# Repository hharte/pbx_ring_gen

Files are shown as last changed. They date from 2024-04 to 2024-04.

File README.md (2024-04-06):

# PBX Ring Generator

This project is a small carrier board for the Power DSine [PCR-SIN06V24F00](https://www.microsemi.com/document-portal/doc_view/10615-pcr-sin06series-datasheet) 4W Ring Generator.  It takes -24VDC as input and supplies isolated 86Vrms / 20Hz ringing current at 4 REN.

Stuffing options are provided for DC-biasing the output.

The board is 1.75”H x 3.93”W for mounting on a 2” relay panel such as the [WE 755A PBX Power Supply](https://github.com/hharte/we755a_ps).

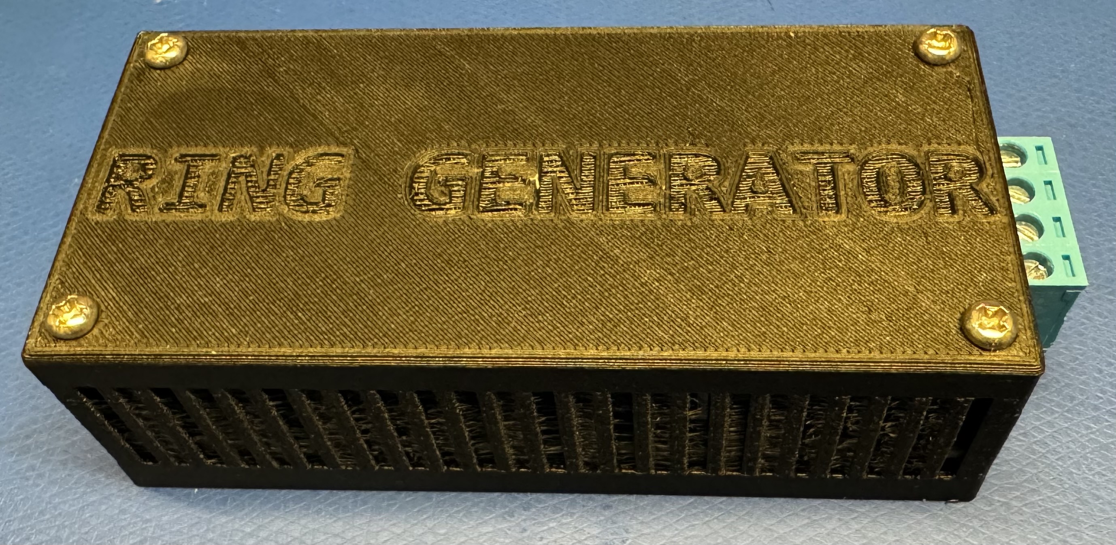
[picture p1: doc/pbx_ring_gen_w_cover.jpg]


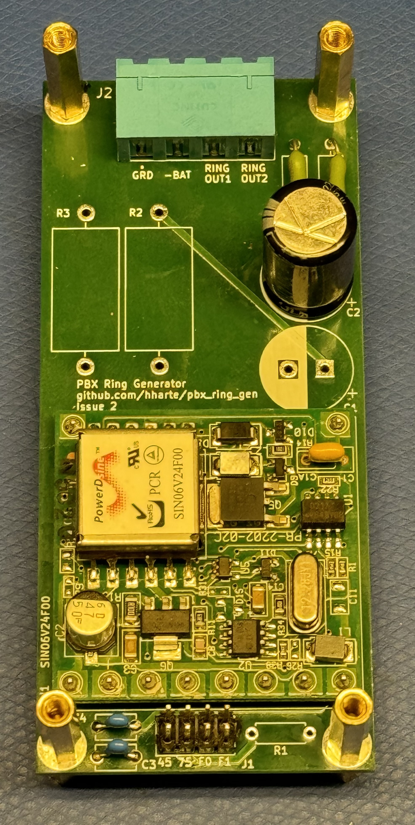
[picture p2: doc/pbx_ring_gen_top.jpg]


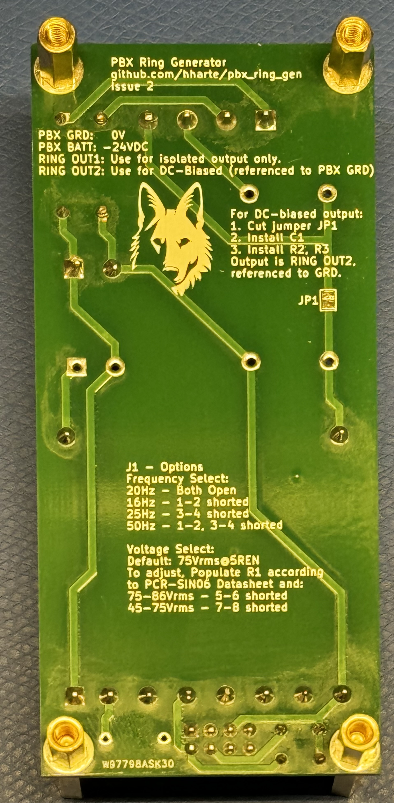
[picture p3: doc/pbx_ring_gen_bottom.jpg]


# Hardware

## PC Board Bill of Materials

[Interactive BOM](https://html-preview.github.io/?url=https://github.com/hharte/pbx_ring_gen/blob/main/hardware/bom/ibom.html)

[Digi-Key Parts List](https://www.digikey.com/en/mylists/list/BBLJD8V3Z4)

## Cover

A 3D-printed cover is included.  [For safety](https://en.wikipedia.org/wiki/UL_94), it’s a good idea to print this using [V-0 PETG](https://prusament.com/materials/prusament-petg-v0/). To mount the board with cover, use 4ea M3-10mm male/female standoffs for the bottom side of the board.  Use 4ea M3-20mm female standoffs for the top side of the board.  Mount the cover with 4ea M3 screws.

# References

* [PCR-SIN06V24F00 Datasheet](https://www.microsemi.com/document-portal/doc_view/10615-pcr-sin06series-datasheet)
* [Telephone Ring Voltage Tech Bulletin](https://www.sandman.com/knowledgebase/ring-voltage-tech-bulletin)

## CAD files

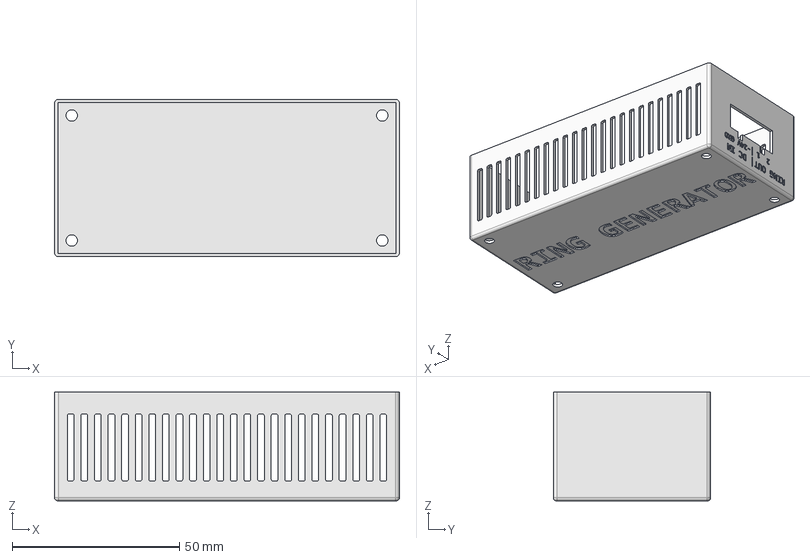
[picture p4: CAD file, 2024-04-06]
enclosure/pbx_ring_gen_cover.FCStd
103.0 x 47.0 x 32.5 mm

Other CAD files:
enclosure/pbx_ring_gen_cover.stl

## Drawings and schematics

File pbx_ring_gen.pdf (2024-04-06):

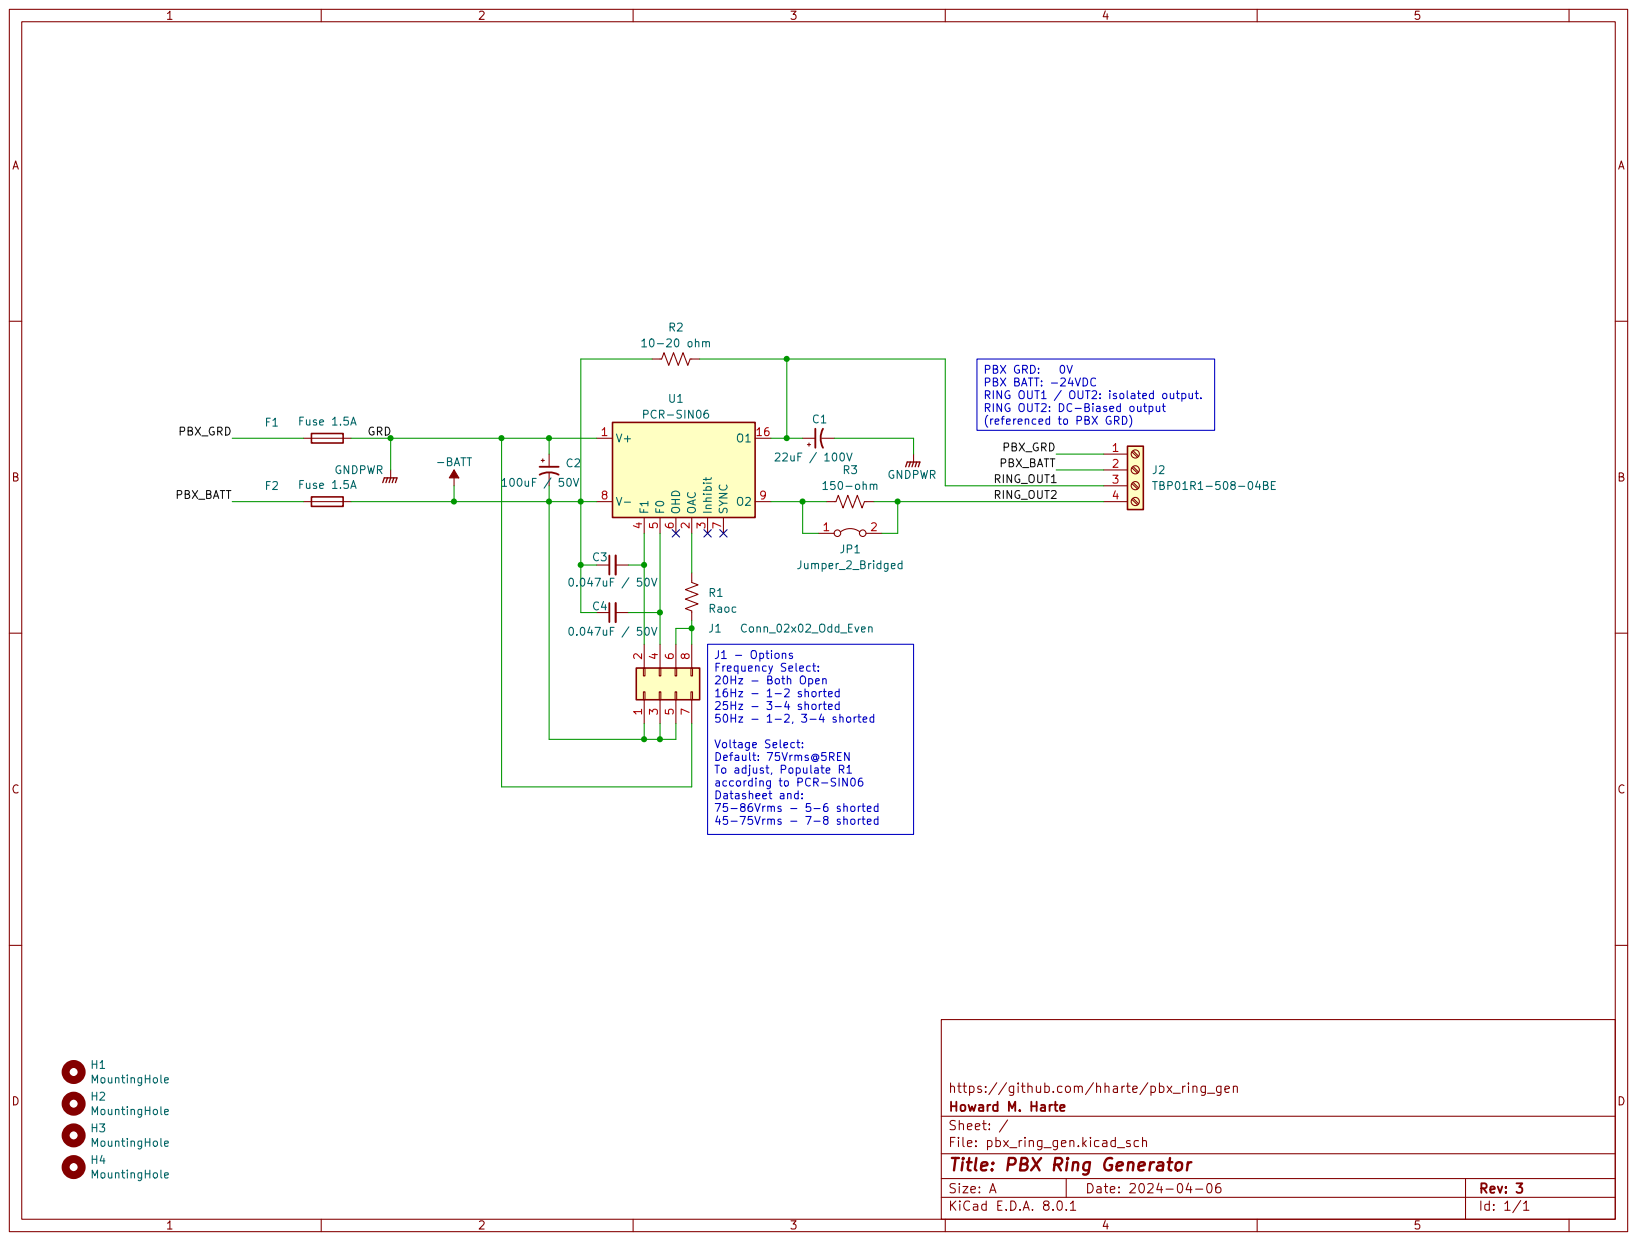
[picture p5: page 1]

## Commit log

2023-06-05 Initial revision.
    [pbx_ring_gen-B_Cu.gbr, pbx_ring_gen-B_Mask.gbr, pbx_ring_gen-B_Silkscreen.gbr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]
2023-06-18 Fix mirrored footprint for PCR-SIN06.
    * The footprint for the PCR-SIN06 ring generator was mirrored in the
    Issue 1 PCB. Install the ring generator on the solder side of the
    PCB for Issue 1.
    * Corrected PCR-SIN06 footprint.
    * Added a jumper that can be cut for DC-biased ringing.
    * Update revision to Issue 2.
    [pbx_ring_gen-B_Cu.gbr, pbx_ring_gen-B_Mask.gbr, pbx_ring_gen-B_Silkscreen.gbr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]
2024-03-23 Update for KiCAD 8.0.1.
    * Update BOM.
    * Update README.md.
    [pbx_ring_gen-B_Cu.gbr, pbx_ring_gen-B_Mask.gbr, pbx_ring_gen-B_Silkscreen.gbr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]
2024-04-06 Update to Rev 3.
    * Round PCB corners.
    * Move connector closer to edge.
    * Update fuses to 1.5A.
    * Create cover for the PBX ring generator.
    [pbx_ring_gen-B_Cu.gbr, pbx_ring_gen-B_Mask.gbr, pbx_ring_gen-B_Silkscreen.gbr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]
